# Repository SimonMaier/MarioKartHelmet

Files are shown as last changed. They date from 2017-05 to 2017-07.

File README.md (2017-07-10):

# IMU-Joystick

**An easy-to-build DIY game controller for computers, based on the MPU6050 gyroscope & Arduino Pro Micro.** 

:video_game:

## Features

The IMU-Joystick is assembled in less than 15 minutes and costs about €5.
When connected to a computer, the board presents itself as a USB joystick. Using the MPU6050, the Arduino measures acceleration & rotation data and maps it to joystick behaviour. The precise mapping of sensor data to joystick axes/buttons can be configured in the Arduino sketch. The controller is automatically detected as a generic joystick device on Linux, Mac, and Windows, without further software:

<p align="center">
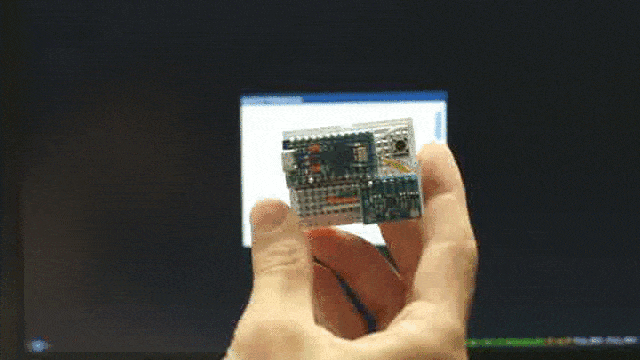
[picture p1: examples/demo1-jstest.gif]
Joystick Demo using jstest-gtk
  
</p>

## Application Examples

For applications check out the [examples](/examples) folder. 
  - `examples/BasicHeadTracker` sets up a generic Joystick with 2 axes and a physical calibration button. It works out of the box  with many games. Below you can watch a video of someone using a head-mounted IMU-Joystick with the `BasicHeadTracker` sketch to collect 89 herrings in *Extreme Tux Racer*:

<p align="center"><a href="https://www.youtube.com/watch?v=GGOQOM26r2M">
  ExtremeTuxRacer with IMU-Joystick video
</a></p>

  - `examples/MarioKartHelmet` demonstrates how to configure IMU-Joystick as a head-mounted game controller, intended for *Mario Kart 64* or *Mario Kart Double Dash*. It allows karts to be controlled through head movements and items triggered via jumping, by wearing a Toad-ish styrofoam hat with an IMU-Joystick inside. After a lot of playing, we can assure that it brings immersive game experience to what is already a great party game :tada:

<p align="center">
  Mario Kart 64 with IMU-Joystick
</p>

## How to build an IMU-Joystick

You can put together your own IMU-Joystick in about 1-2h. Except for mounting pin headers, no soldering is required.

### 1. Get the hardware
  - [Arduino(-compatible) Pro Micro](https://www.aliexpress.com/item/New-Pro-Micro-for-arduino-ATmega32U4-5V-16MHz-Module-with-2-row-pin-header-For-Leonardo/32773740303.html), any ATmega32U4-based Arduino will do.
  - [MPU6050](https://www.aliexpress.com/item/versandkostenfrei-gy-521-mpu-6050-mpu6050-modul-3-achse-analog-Gyro-Sensoren-beschleunigungsmesser-modul/32315092057.html) (GY-521 breakout), a low-cost accelerometer + gyroscope.
  - mini-sized [breadboard](https://www.aliexpress.com/item/Mini-Breadboard-Protoboard-DIY-Kit-Universal-Transparent-Solderless-SYB-170-Breadboard-170Tie-points-Prototype-Boards-35X47MM/3271799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)
  - (optional) [push buttons](https://www.aliexpress.com/item/100pcs-6-6-5mm-4pin-Quality-Mini-Micro-Momentary-Tactile-Push-Button-Switch/32753141267.html)
  - some wire to make breadboard connections.

**Total material cost** as of June 2017: €2,72 Pro Micro + €0.93 GY-521 + €0.80 breadboard = **4.45€**, shipping included.

### 2. Assemble the hardware
Solder pin headers where needed; Place Pro Micro, GY-521 & wire on breadboard as follows:
<p align="center">
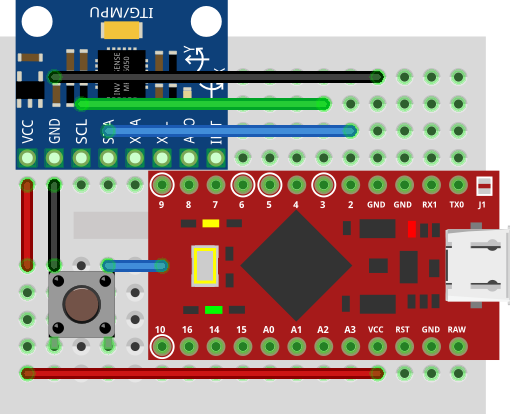
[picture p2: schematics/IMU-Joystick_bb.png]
Breadboard Assembly
  
</p>
Note that Pro Micro 8 & 9 do not need to connect to the MPU6050.

### 3. Get the software
- [Arduino IDE (>=1.6.6)](https://www.arduino.cc/en/main/software)
- external Arduino libraries:
  - [i2cdevlib](https://github.com/jrowberg/i2cdevlib)
    collection (at least [I2Cdev](https://github.com/jrowberg/i2cdevlib/tree/master/Arduino/I2Cdev) and [MPU6050](https://github.com/jrowberg/i2cdevlib/tree/master/Arduino/MPU6050)).
    
    Follow the [installation instructions on the website](https://www.i2cdevlib.com/usage), or copy the folders `i2cdevlib/Arduino/I2Cdev` and `i2cdevlib/Arduino/MPU6050` from the project repository into your Arduino [libraries directory](https://www.arduino.cc/en/hacking/libraries) (`~/Arduino/libraries/` on Linux).
  - [ArduinoJoystickLibrary (>=2.0)](https://github.com/MHeironimus/ArduinoJoystickLibrary)
  
    Copy the folder `ArduinoJoystickLibrary/Joystick` to your Arduino libraries directory.
- This repository. Copy any folder from `examples` into your Arduino directory.
    
### 4. Upload the software

Install the required libraries and upload the one of the example sketches to your Pro Micro board. Note that you might need to select Arduino Leonardo as a target board, when using the Arduino GUI.

### 5. Enjoy!

We recommend that you play some *Mario Kart 64* with your IMU Joystick used as a head tracker (on ArchLinux).
Do the following steps:
  - Step 0: Upload the [MarioKartHelmet](examples/MarioKartHelmet/MarioKartHelmet.ino) sketch
  - Step 1: `~# pacman -S mupen64plus`
  - Step 2: Add controller specification to `/usr/share/mupen64plus/InputAutoCfg.ini` file.
  - Step 3: Legally obtain ROM file for *Mario Kart 64*.
  - Step 4: Connect controller & carefully place it on top of your head
  - Step 5: `~# mupen64plus --fullscreen --gfx mupen64plus-video-glide64 <location-of-ROM-file.n64>`
  - Step 6: \o/ Control race cars using your head movements.

## How to *develop* the controller

This section lists some tools, that we found useful during development.

  - the linux command line tool package `joyutils` allow testing and simple debugging of joysticks, e.g. with `~$ jstest /dev/input/js0`. A graphical version [jstest-gtk](https://github.com/Grumbel/jstest-gtk) is also available.
  - the N64 emulator `mupen64plus` is useful to evaluate gameplay experience. Alternatively, the free game `extremetuxracer` also has Joystick support.

## Issues & Contributing

If you have any questions or problems, feel free to communicate with us using Github Issues. Contributed PRs will be merged.

## Authors

 Chris, Tobias, Simon, Sean, and anybody in the contributers list.

## License

[GNU GPL v3](https://github.com/SimonMaier/MarioKartHelmet/blob/master/LICENSE), except for this introduction (`README.md`) which is .

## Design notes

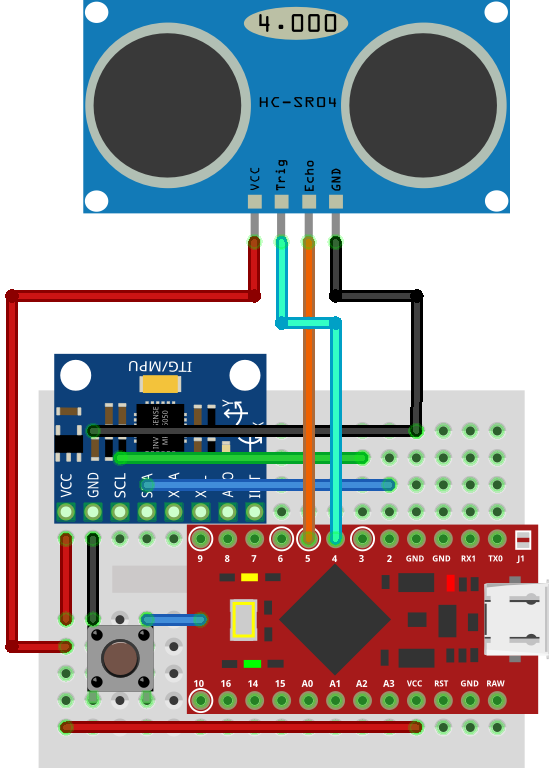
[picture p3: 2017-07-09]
schematics/IMU-Joystick_with_HC-SR04_bb.png

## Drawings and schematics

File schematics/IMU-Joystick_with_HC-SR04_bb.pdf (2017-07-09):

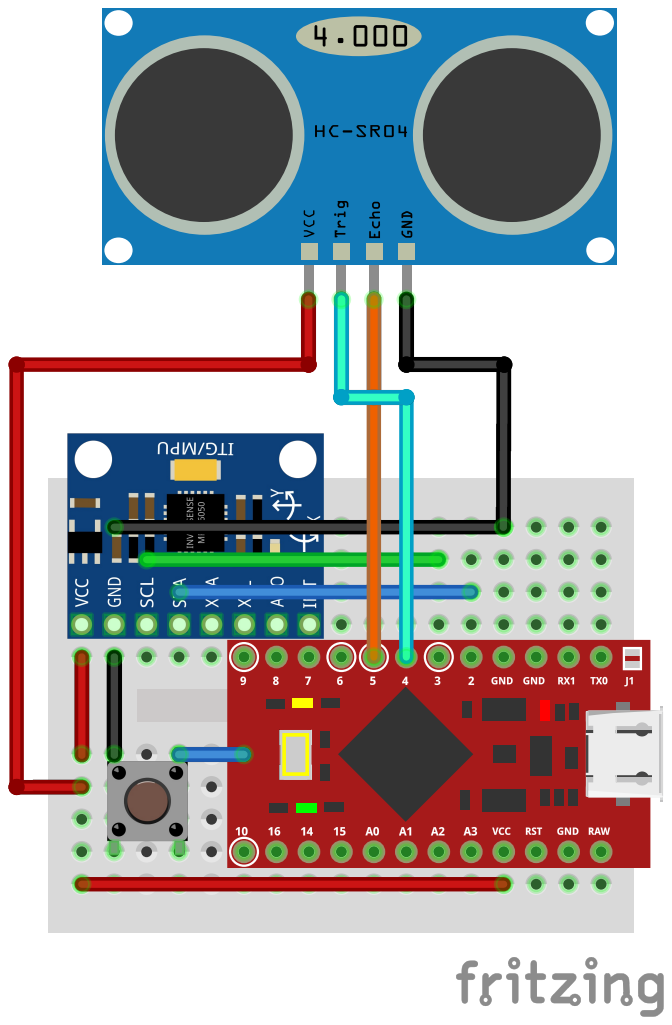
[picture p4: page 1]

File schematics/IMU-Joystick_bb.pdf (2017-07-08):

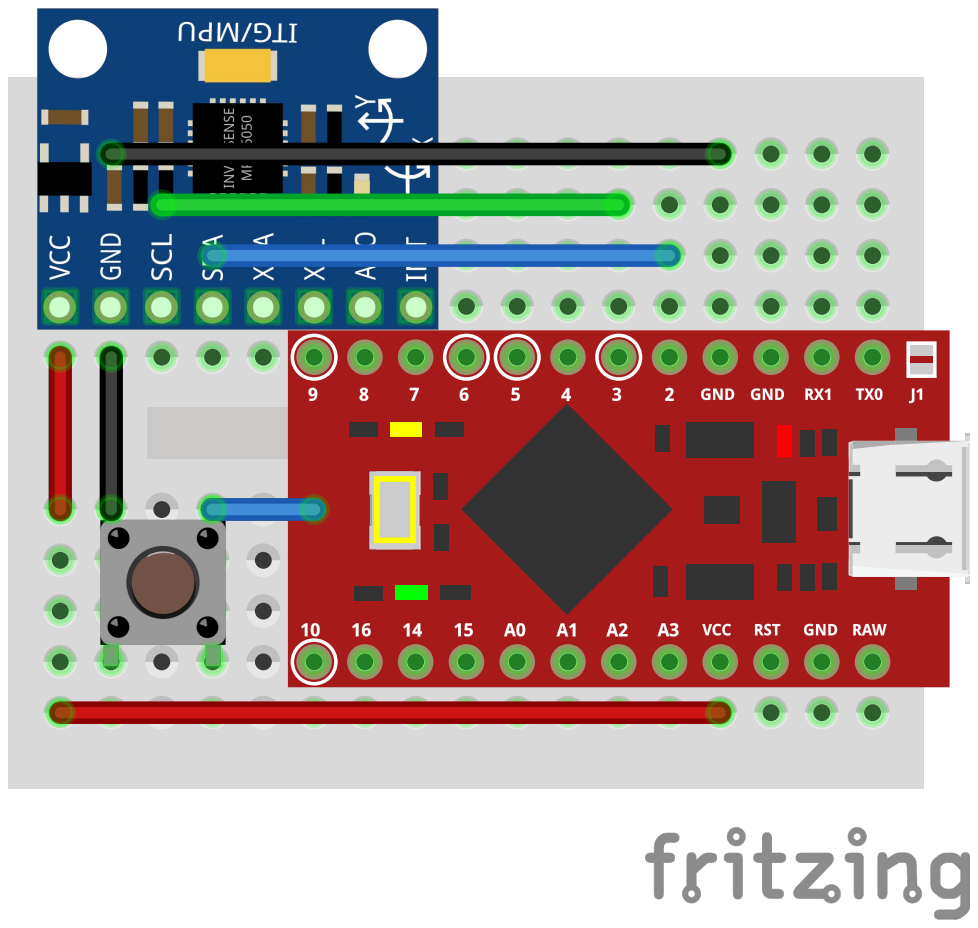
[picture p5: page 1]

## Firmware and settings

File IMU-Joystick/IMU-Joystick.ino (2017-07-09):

#include "Wire.h"
#include "I2Cdev.h"
#include "MPU6050_6Axis_MotionApps20.h"
#include "Joystick.h"

/*  The  minimal IMU-Joystick template file.
    For runnable examples demos check out the /examples/ directory. */

// Initialize Joystick with 2 buttons and 2 axes (X,Y)
Joystick_ Joystick(JOYSTICK_DEFAULT_REPORT_ID,
    JOYSTICK_TYPE_MULTI_AXIS, 2, 0, true, true, false,
    false, false, false, false, false, false, false, false);
#define SCALING 3        // max Joystick value  at 90deg/SCALING.

MPU6050 mpu;
// MPU control/status vars
bool dmpReady = false;   // set true if DMP init was successful
uint8_t mpuIntStatus;    // interrupt status byte from MPU
uint8_t devStatus;       // for return status checking (0 = success, !0 = error)
uint16_t packetSize;     // expected DMP packet size (default is 42 bytes)
uint16_t fifoCount;      // current FIFO length
uint8_t fifoBuffer[64];  // FIFO storage buffer
// MPU orientation/motion vars
Quaternion q;            // [w, x, y, z]
VectorFloat gravity;     // [x, y, z]
float ypr[3];            // [yaw, pitch, roll]
float pitchOffset = 0;   // set with push button press
float rollOffset = 0;

// ISR to indicate new MPU data
#define MPU_INTERRUPT_PIN 7
volatile bool mpuInterrupt = false;
void dmpDataReady() { mpuInterrupt = true; }

#define BUTTON_PIN A0
bool buttonPressed = false;


void setup() {

    // set up USB joystick
    Joystick.setXAxisRange(-512, 511);
    Joystick.setYAxisRange(-512, 511);
    // if Joystick is initiated with false, Joystick.sendState() must be called
    // to send updated values. Useful because state transmission is
    // comparatively slow and should be minimized!
    Joystick.begin(false);

    // set up push button
    pinMode(BUTTON_PIN, INPUT_PULLUP);

    // set up MPU6050
    pinMode(MPU_INTERRUPT_PIN, INPUT);
    Wire.begin();
    Wire.setClock(400000);
    mpu.initialize();
    devStatus = mpu.dmpInitialize();

    if (devStatus == 0) {
        mpu.setDMPEnabled(true);
        // set up ISR for MPU6050 FIFO "data ready"-interrupts
        attachInterrupt(digitalPinToInterrupt(MPU_INTERRUPT_PIN),
                        dmpDataReady, RISING);
        mpuIntStatus = mpu.getIntStatus();
        dmpReady = true;
        packetSize = mpu.dmpGetFIFOPacketSize();
    } else {
       fail();
    }
}


void loop() {

    // push button: when released, take current pitch & roll as offset
    if (digitalRead(BUTTON_PIN) == LOW && !buttonPressed) {
        buttonPressed = true;
    } else if (digitalRead(BUTTON_PIN) == HIGH && buttonPressed) {
        pitchOffset = ypr[1];
        rollOffset = ypr[2];
        buttonPressed = false;
    }

    // wait for MPU interrupt or extra packet(s) available
    while (!mpuInterrupt && fifoCount < packetSize) { }
    // reset interrupt flag and get INT_STATUS byte
    mpuInterrupt = false;
    mpuIntStatus = mpu.getIntStatus();
    fifoCount = mpu.getFIFOCount();

    // check for DMP data ready interrupt (this should happen frequently)
    if (mpuIntStatus & 0x02) {
        while (fifoCount < packetSize) fifoCount = mpu.getFIFOCount();

        // read a packet from FIFO
        mpu.getFIFOBytes(fifoBuffer, packetSize);
        fifoCount -= packetSize;

        // process packet
        mpu.dmpGetQuaternion(&q, fifoBuffer);
        mpu.dmpGetGravity(&gravity, &q);
        mpu.dmpGetYawPitchRoll(ypr, &q, &gravity);

        // SCALING of 3 means that max value is achieved
        // at around 30° tilt instead of 90°.
        Joystick.setXAxis((int)((ypr[2]-rollOffset)  * 1024/M_PI*SCALING));
        Joystick.setYAxis((int)((ypr[1]-pitchOffset) * 1024/M_PI*SCALING));
        Joystick.sendState(); // this is slow; might cause FIFO overflow.

        /////////////////////////////////////////////
        // send custom joystick behavior
        // based on acceleration & gyro data here.
        // ...
        //
        ////////////////////////////////////////////

    }

    // check for MPU FIFO overflow
    if ((mpuIntStatus & 0x10) || fifoCount == 1024) {
        mpu.resetFIFO();
    }
}

void fail() {
    while (1) {
        RXLED0;
        delay(250);
        RXLED1;
        delay(250);
    }
}

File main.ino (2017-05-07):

// I2Cdev and MPU6050 must be installed as libraries, or else the .cpp/.h files
// for both classes must be in the include path of the project
#include "I2Cdev.h"
#include "MPU6050.h"
#include "Keyboard.h"
#include "Wire.h"

#define LEFT_THRESHOLD          -5500
#define LEFT_THRESHOLD_RELEASE  -5000
#define RIGHT_THRESHOLD          5500
#define RIGHT_THRESHOLD_RELEASE  5000
#define SPEED_THRESHOLD         -6000
#define SLOW_THRESHOLD           1000

MPU6050 accelgyro;  // I2C address is 0x68
int16_t ax, ay, az, gx, gy, gz;

void setup() {
    Wire.begin();
    Keyboard.begin();
    accelgyro.initialize();

    Serial.begin(115200);
    Serial.println("Testing I2C connection...");
    Serial.println(accelgyro.testConnection() ? "MPU6050 connection successful" : "MPU6050 connection failed");
}

void loop() {
    // read raw accel/gyro measurements from device
    accelgyro.getMotion6(&ax, &ay, &az, &gx, &gy, &gz);

    // trigger keypresses according to the sensor values
    press_controls(ax, ay, az, gx, gy, gz);
    release_controls(ax, ay, az, gx, gy, gz);
    shoot_item(gx, gy, gz);

/*  Serial.print("a/g:\t");
    Serial.print(ax); Serial.print("\t");
    Serial.print(ay); Serial.print("\t");
    Serial.print(az); Serial.print("\t");
    Serial.print(gx); Serial.print("\t");
    Serial.print(gy); Serial.print("\t");
    Serial.println(gz);*/
}


void press_controls(int16_t ax, int16_t ay, int16_t az, int16_t gx, int16_t gy, int16_t gz) {
    // Trigger keypresses in case helmet is tilted to left, right, front, or back.
    if (ay <  LEFT_THRESHOLD) {
        Keyboard.press(KEY_LEFT_ARROW);
        Serial.println("Moving Left");
        TXLED1;  // turn on onboard LED
    }
    else if (ay > RIGHT_THRESHOLD) {
        Keyboard.press(KEY_RIGHT_ARROW);
        Serial.println("Moving Right");
        TXLED1;  // turn on onboard LED
    }
    if (ax < SPEED_THRESHOLD) {
        Keyboard.press(KEY_LEFT_SHIFT);
        //Serial.println("Speeding");
    }
    else if (ax > SLOW_THRESHOLD) {
        Keyboard.press(KEY_LEFT_CTRL);
        Serial.println("Slowing down");
    }
}

void release_controls(int16_t ax, int16_t ay, int16_t az, int16_t gx, int16_t gy, int16_t gz) {
    // release pressed keys when tilt back in normal range
    if (ay > LEFT_THRESHOLD_RELEASE && ay < RIGHT_THRESHOLD_RELEASE) {
        Keyboard.release(KEY_RIGHT_ARROW);
        Keyboard.release(KEY_LEFT_ARROW);
        //Serial.println("Release Y");
        TXLED0; // turn off onboard LED
    }
    if (ax > SPEED_THRESHOLD && ax < SLOW_THRESHOLD) {
        Keyboard.release(KEY_LEFT_SHIFT);
        Keyboard.release(KEY_LEFT_CTRL);
        //Serial.println("Release X");
    }
}

void shoot_item(int16_t gx, int16_t gy, int16_t gz) {
    if (abs(gy) > 7000) {
        Keyboard.write('y');
        Serial.println("Shooting");
    }
}

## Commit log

2017-05-07 Initital commit : Accelerometer and keyboard translation working
2017-05-07 used #define, fixed formatting
    [main.ino]
2017-05-07 used onboard LED to indicate left/right turns
2017-05-07 used onboard LED to indicate left/right turns (2)
2017-05-07 used onboard LED to indicate left/right turns (3)
2017-07-04 Added test sketch for MPU6050 IMU with DMP enabled and FIFO push mode (using interrupts on pin 7)
2017-07-04 Working test sketch to send IMU pitch and roll to PC, emulating a 2-axis Joystick with 4 extra buttons
2017-07-04 added functioning Joystick controller (missing: Jump + Calibration)
    [IMU-Joystick.ino]
2017-07-04 Jumping works (again) in IMU-Joystick.ino
2017-07-04 Added the code for the ultrasonic-sensor
2017-07-04 Corrections from working session 0704
    [IMU-Joystick.ino]
2017-07-08 added Fritzing files/images
    [IMU-Joystick.fzz]
2017-07-08 Fritzing fix
    [IMU-Joystick.fzz]
2017-07-08 README.md: Inserted jstest gif
2017-07-09 restructured repo; any old material is now moved to other
    [IMU-Joystick.fzz]
2017-07-09 Fixed accel: normalize pitch by subtracting it's cumulative average
    [MarioKartHelmet.ino]
2017-07-09 turned IMU-Joystick/IMU-Joystick.ino into basic Joystick example
2017-07-09 added 2nd Fritzing with distance sensor connected
    [IMU-Joystick_with_HC-SR04.fzz]
